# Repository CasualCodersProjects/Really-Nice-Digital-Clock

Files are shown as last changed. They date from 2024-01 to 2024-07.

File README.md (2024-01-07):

# Digital Clock Hardware

## Notice:
There is a hardware change between the 8 clocks sold on Tindie and these. The original production clocks from tindie are:  
- Missing a copper trace between the 3v3 line and the 3v3 output of the LDO. This is corrected with a hand-assembled solder bridge.  
- The I2C lines are shifted right by one pin. The tindie version uses GPIO21 for SDA and GPIO33 for SCL.  
- The Tindie clocks have a manually soldered bodge to move one of the binary coded digits off GPIO 46, which is an input only strapping pin.

## Description
This is an internet connected Clock which synchronizes with NTP servers to perpetually serve an accurate time. It is unable to keep very good time by itself. As such, it requires a stable, consistent network connection to show reliable time. With that, it should always be acctute within a second or so. To improve accuracy, you could modify the firmware to check every hour or half hour instead of once per day.  

It's built using BCD Decoders and 1.5" Seven segment displays for a nice clean look. It also utilizes an ambient light sensor to automatically brighten and dim to match the room light.  

This clock serves it's own webpage for configuration. Upon first boot, it activates an access point ssid `NiceClock`, password `MinesBigger`. Connect to the default gateway `192.168.4.1` to configure the clock and provide network credentials. Once credentials are provided, it should instantly connect and acquire the network time.  
To view the device's IP address, press the boot button on the rear.

## Hacking
This device openly exposes both a TTL UART and JTAG port on the rear of te board, near the ESP Module. You can also use the USB Port to program and upload code. While holding the boot button, then press reset. This enters the ESP32 into bootloader mode, and allows you to reflash new firmware or filesystem to the device.

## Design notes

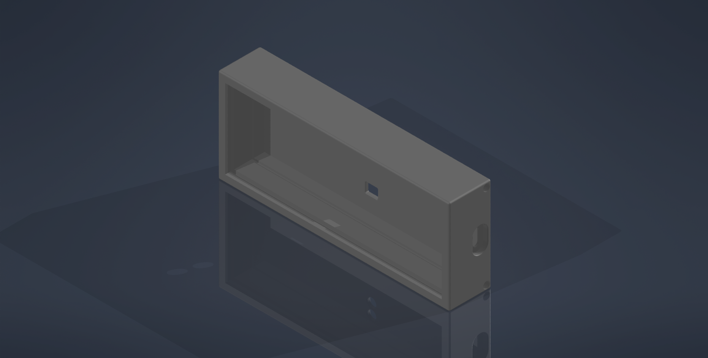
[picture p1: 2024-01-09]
Images/Case1.png

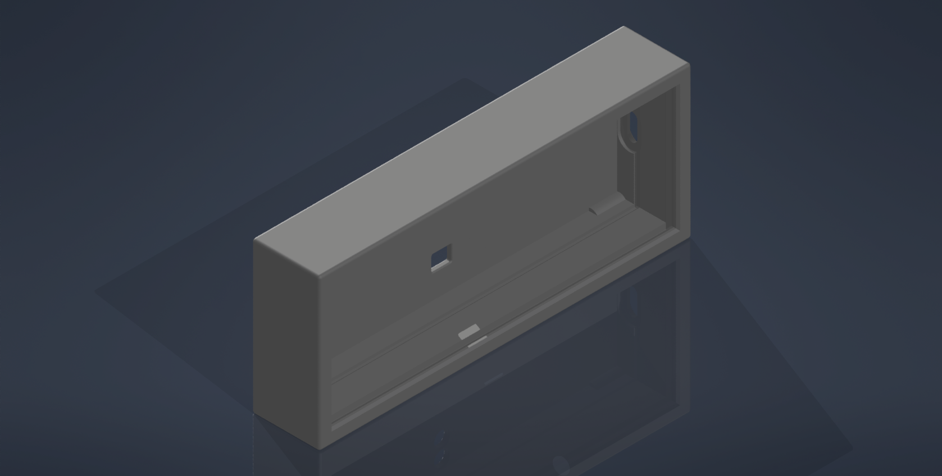
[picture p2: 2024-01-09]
Images/Case.png

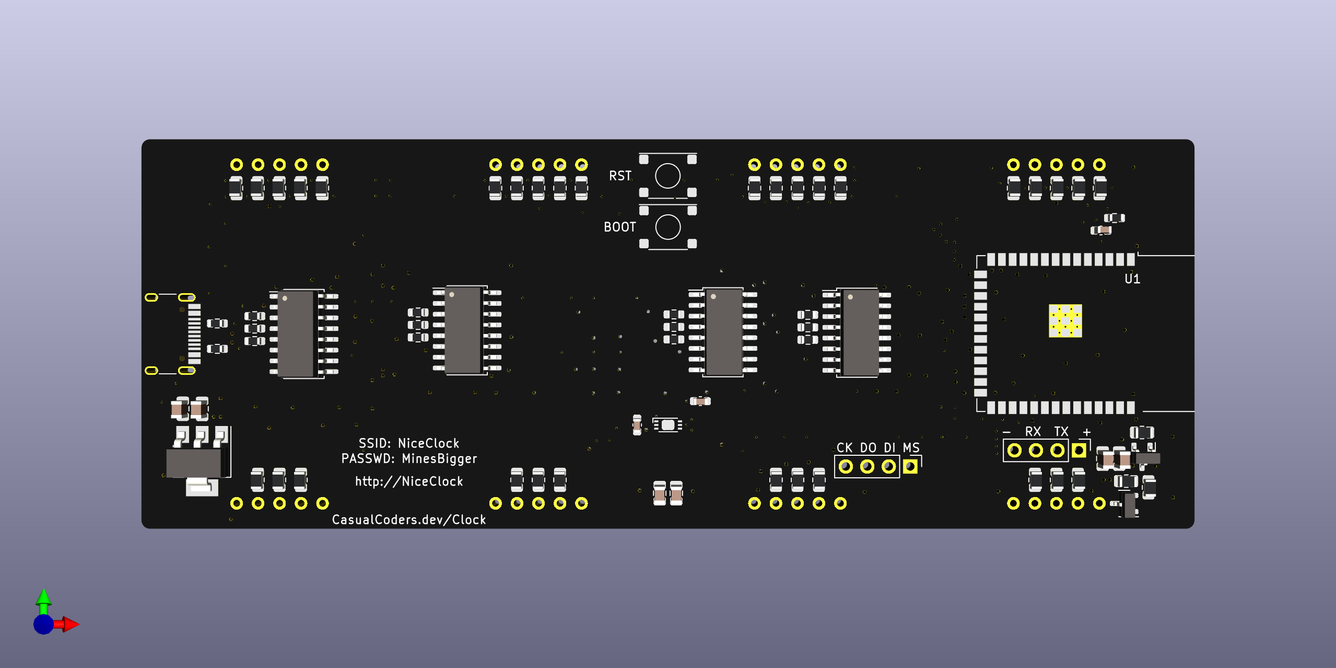
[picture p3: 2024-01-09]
Images/PCB_Render_RevB.png

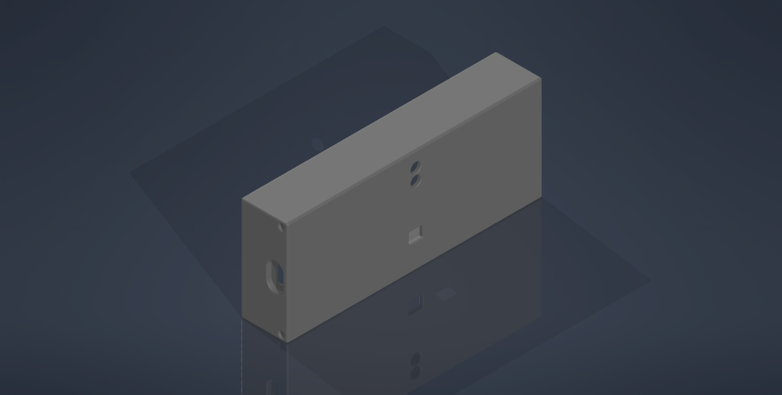
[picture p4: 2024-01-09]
Images/Case2.png

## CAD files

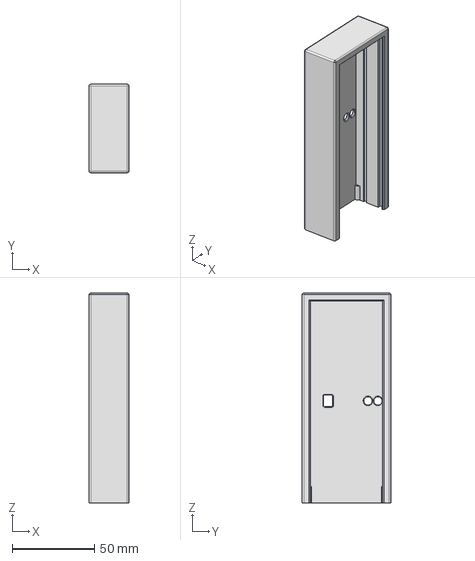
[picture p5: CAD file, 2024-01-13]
Case/V2.1 Case.stp
24.1 x 53.8 x 127.5 mm

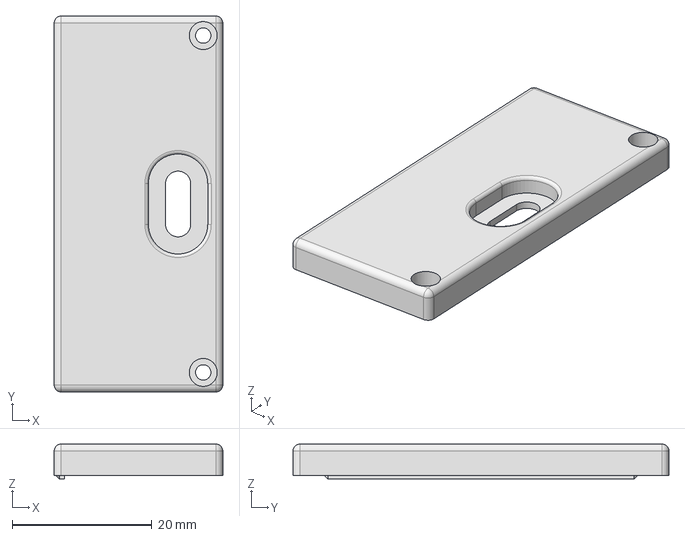
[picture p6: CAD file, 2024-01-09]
Case/V2.0 Lid.stp
24.1 x 53.8 x 5.00 mm

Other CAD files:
Case/V2.0 Lid.ipt
Case/V2.0 Lid.stl
Case/V2.1 Case.ipt
Case/V2.1 Case.stl

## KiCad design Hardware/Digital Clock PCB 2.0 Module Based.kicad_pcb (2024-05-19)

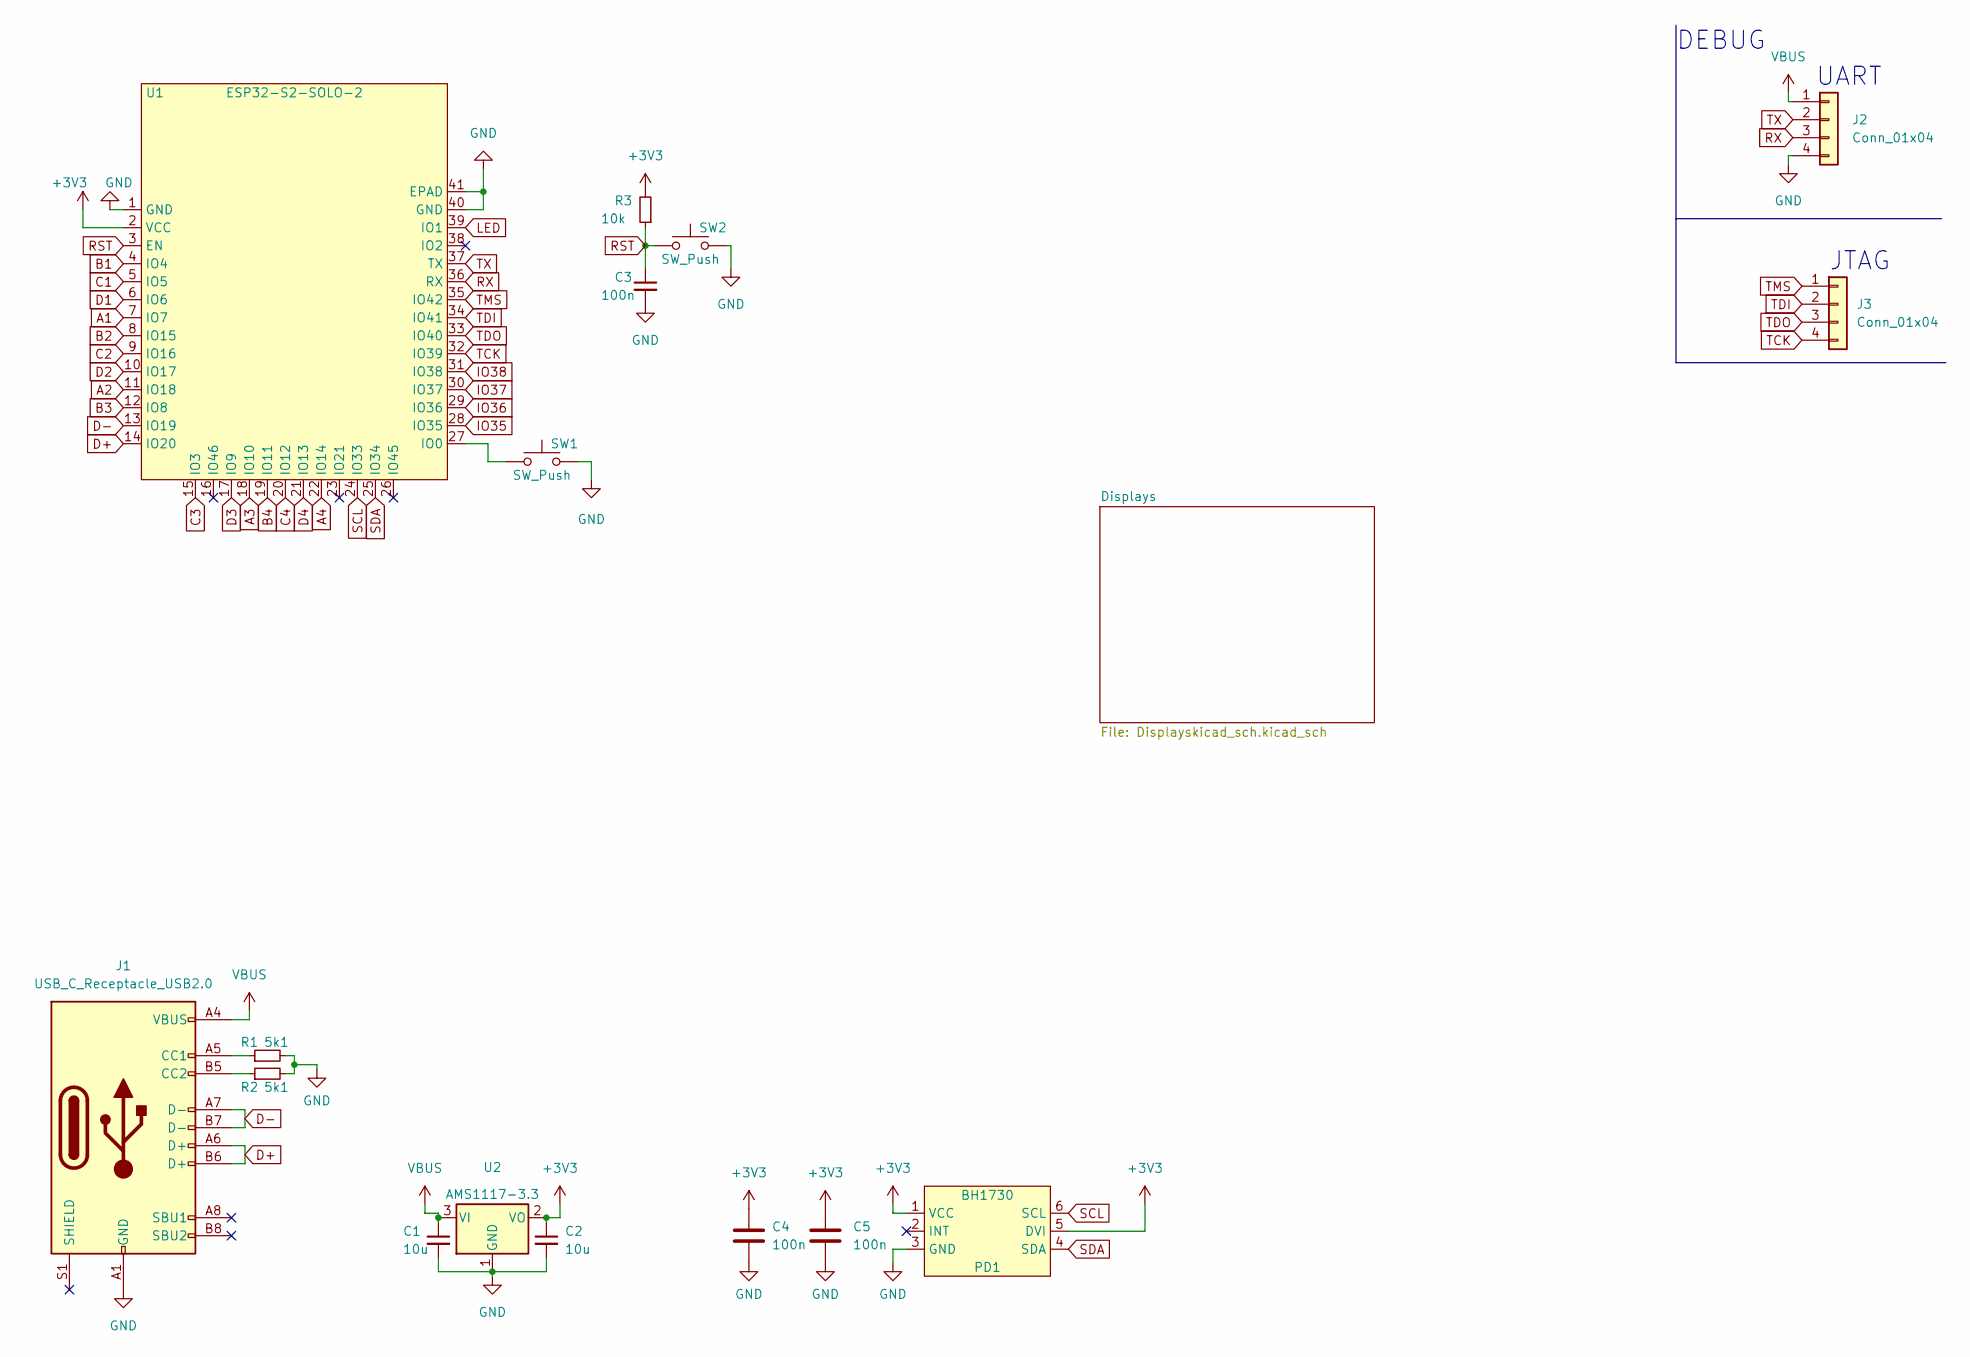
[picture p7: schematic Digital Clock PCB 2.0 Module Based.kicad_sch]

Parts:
C1, C2: 10u; C_0805_2012Metric
C3, C4, C5: 100n; C_0603_1608Metric
J1: USB_C_Receptacle_USB2.0; USB_C_Receptacle_HRO_TYPE-C-31-M-12
J2, J3: Conn_01x04; PinHeader_1x04_P2.54mm_Vertical
PD1: BH1730; WSOF6
R1, R2: 5k1; R_0603_1608Metric
R3: 10k; R_0603_1608Metric
SW1, SW2: SW_Push; 5.2mm_Tactile_Push_Button
U1: ESP32-S2-SOLO-2; ESP32-S3-WROOM-1
U2: AMS1117-3.3; SOT-223-3_TabPin2

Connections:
+3V3: C2.1, C4.1, C5.1, PD1.1 (VCC), PD1.5 (DVI), R3.2, U1.2 (VCC), U2.2 (VO); also elsewhere on the board
A1: U1.7 (IO7); also elsewhere on the board
A2: U1.11 (IO18); also elsewhere on the board
A3: U1.18 (IO10); also elsewhere on the board
A4: U1.22 (IO14); also elsewhere on the board
B1: U1.4 (IO4); also elsewhere on the board
B2: U1.8 (IO15); also elsewhere on the board
B3: U1.12 (IO8); also elsewhere on the board
B4: U1.19 (IO11); also elsewhere on the board
C1: U1.5 (IO5); also elsewhere on the board
C2: U1.9 (IO16); also elsewhere on the board
C3: U1.15 (IO3); also elsewhere on the board
C4: U1.20 (IO12); also elsewhere on the board
D1: U1.6 (IO6); also elsewhere on the board
D2: U1.10 (IO17); also elsewhere on the board
D3: U1.17 (IO9); also elsewhere on the board
D4: U1.21 (IO13); also elsewhere on the board
D+: J1.A6 (D+), J1.B6 (D+), U1.14 (IO20)
D-: J1.A7 (D-), J1.B7 (D-), U1.13 (IO19)
GND: C1.2, C2.2, C3.2, C4.2, C5.2, J1.A1 (GND), J1.A12 (GND), J1.B1 (GND), J1.B12 (GND), J2.4, PD1.3 (GND), R1.2, R2.2, SW1.2, SW2.2, U1.1 (GND), U1.40 (GND), U1.41 (EPAD), U2.1 (GND); also elsewhere on the board
IO35: U1.28 (IO35); also elsewhere on the board
IO36: U1.29 (IO36); also elsewhere on the board
IO37: U1.30 (IO37); also elsewhere on the board
IO38: U1.31 (IO38); also elsewhere on the board
LED: U1.39 (IO1); also elsewhere on the board
unnamed: J1.A5 (CC1), R1.1
unnamed: J1.B5 (CC2), R2.1
unnamed: SW1.1, U1.27 (IO0)
RST: C3.1, R3.1, SW2.1, U1.3 (EN)
RX: J2.3, U1.36 (RX)
SCL: PD1.6 (SCL), U1.24 (IO33)
SDA: PD1.4 (SDA), U1.25 (IO34)
TCK: J3.4, U1.32 (IO39)
TDI: J3.2, U1.34 (IO41)
TDO: J3.3, U1.33 (IO40)
TMS: J3.1, U1.35 (IO42)
TX: J2.2, U1.37 (TX)
VBUS: C1.1, J1.A4 (VBUS), J1.A9 (VBUS), J1.B4 (VBUS), J1.B9 (VBUS), J2.1, U2.3 (VI); also elsewhere on the board

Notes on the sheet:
DEBUG
UART
JTAG

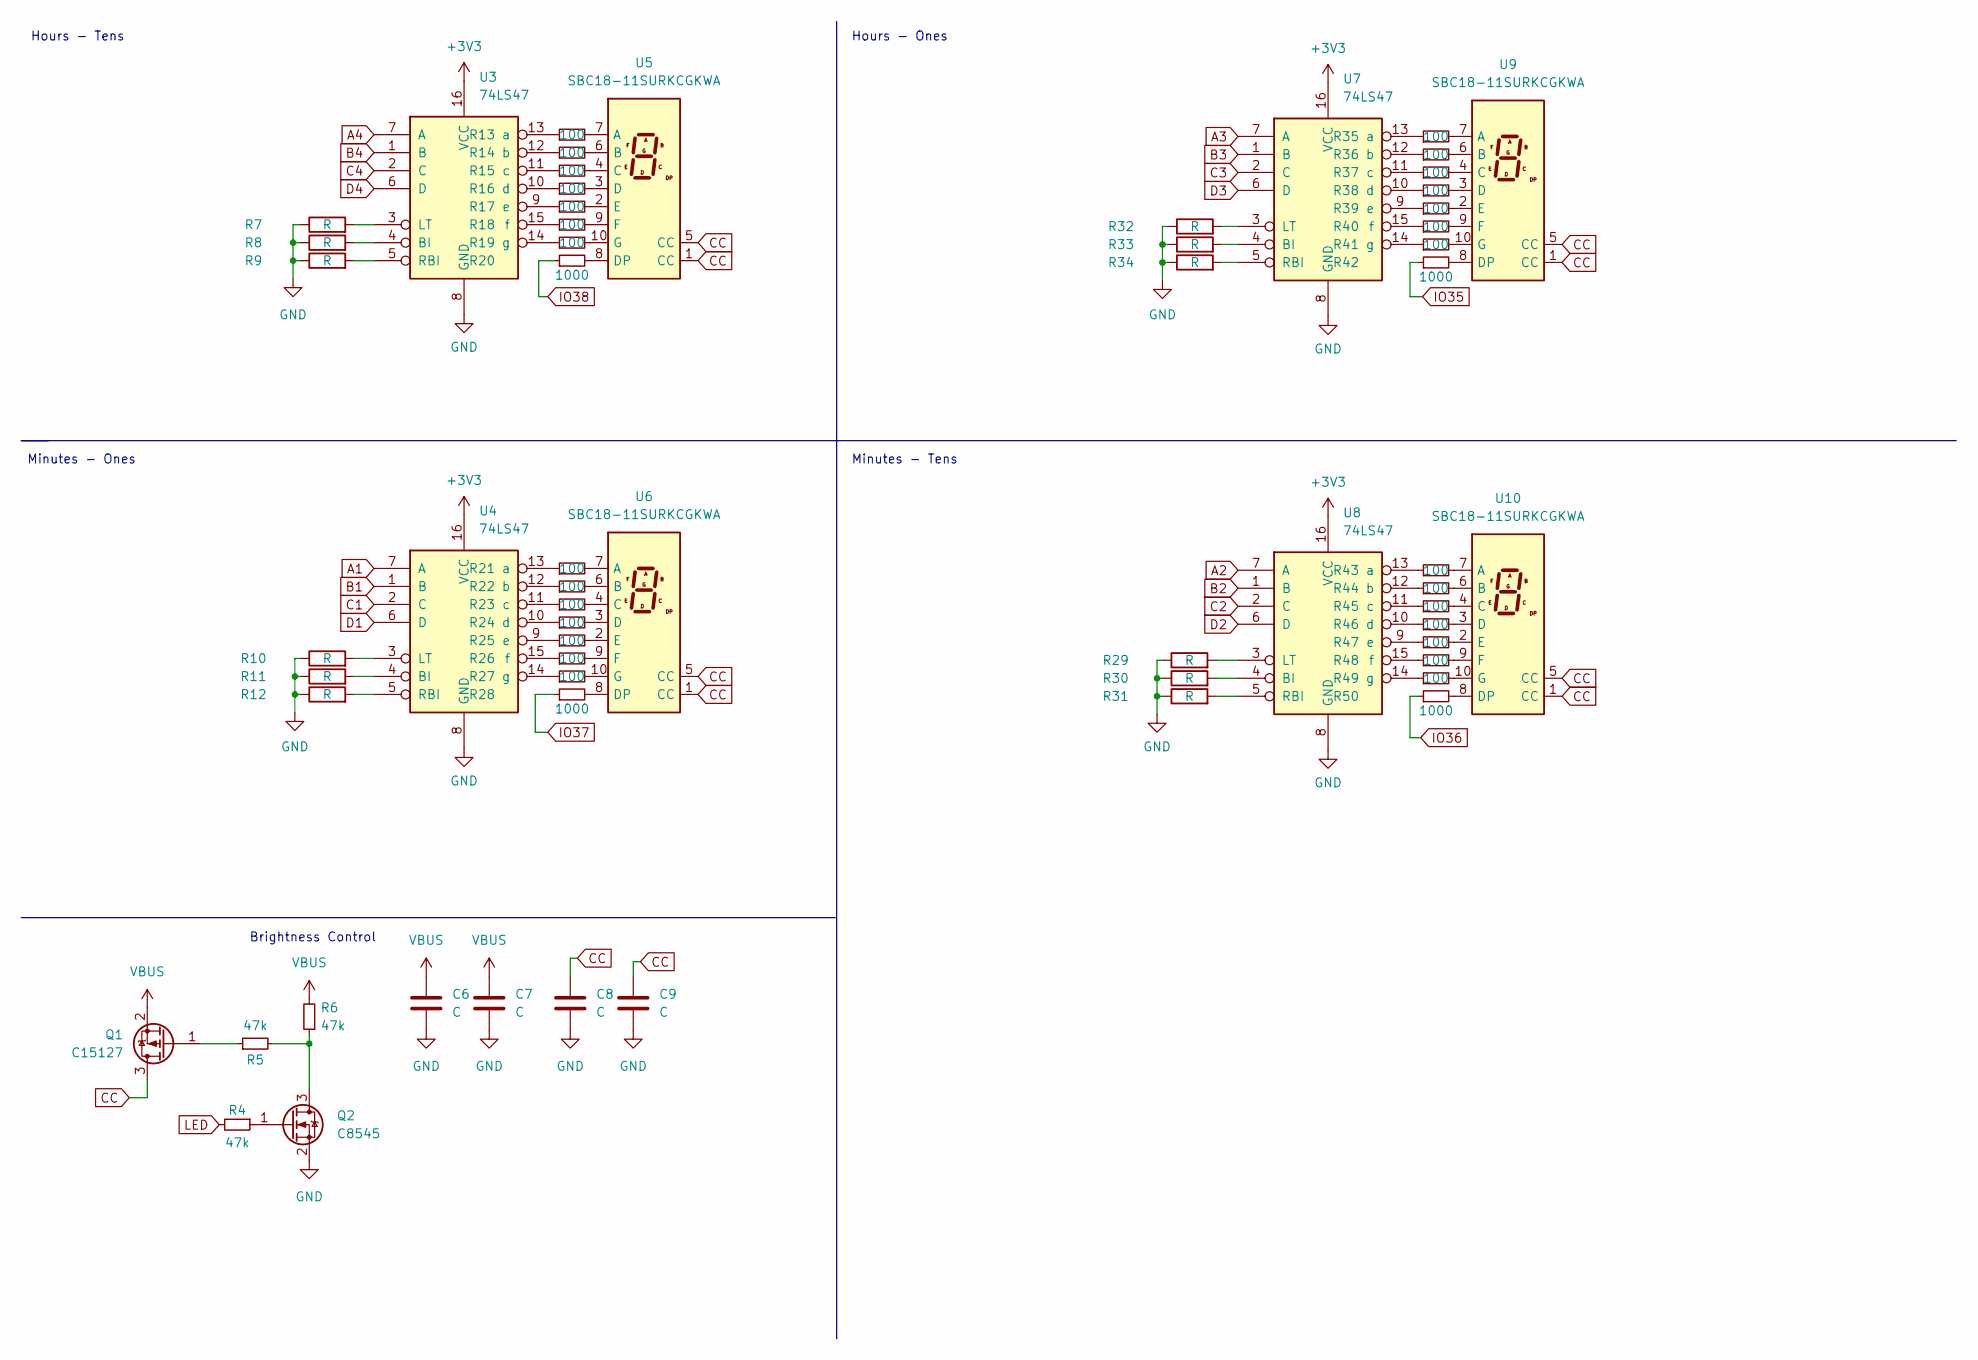
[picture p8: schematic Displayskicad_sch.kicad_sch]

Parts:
C6, C7, C8, C9: C; C_0805_2012Metric
Q1: C15127; SOT-23
Q2: C8545; SOT-23
R4, R5, R6: 47k; R_0805_2012Metric
R7, R8, R9, R10, R11, R12, R29, R30, R31, R32, R33, R34: R; R_0603_1608Metric
R13, R14, R15, R16, R17, R18, R19, R21, R22, R23, R24, R25, R26, R27, R35, R36, R37, R38, R39, R40, R41, R43, R44, R45, R46, R47, R48, R49: 100; R_0805_2012Metric
R20, R28, R42, R50: 1000; R_0805_2012Metric
U3, U4, U7, U8: 74LS47; SOIC-16_4.55x10.3mm_P1.27mm
U5, U6, U9, U10: SBC18-11SURKCGKWA; Segment_Display_1-5_inch

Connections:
+3V3: U3.16 (VCC), U4.16 (VCC), U7.16 (VCC), U8.16 (VCC); also elsewhere on the board
A1: U4.7 (A); also elsewhere on the board
A2: U8.7 (A); also elsewhere on the board
A3: U7.7 (A); also elsewhere on the board
A4: U3.7 (A); also elsewhere on the board
B1: U4.1 (B); also elsewhere on the board
B2: U8.1 (B); also elsewhere on the board
B3: U7.1 (B); also elsewhere on the board
B4: U3.1 (B); also elsewhere on the board
C1: U4.2 (C); also elsewhere on the board
C2: U8.2 (C); also elsewhere on the board
C3: U7.2 (C); also elsewhere on the board
C4: U3.2 (C); also elsewhere on the board
CC: C8.1, C9.1, Q1.3 (D), U5.1 (CC), U5.5 (CC), U6.1 (CC), U6.5 (CC), U9.1 (CC), U9.5 (CC), U10.1 (CC), U10.5 (CC)
D1: U4.6 (D); also elsewhere on the board
D2: U8.6 (D); also elsewhere on the board
D3: U7.6 (D); also elsewhere on the board
D4: U3.6 (D); also elsewhere on the board
GND: C6.2, C7.2, C8.2, C9.2, Q2.2 (S), R7.1, R8.1, R9.1, R10.1, R11.1, R12.1, R29.1, R30.1, R31.1, R32.1, R33.1, R34.1, U3.8 (GND), U4.8 (GND), U7.8 (GND), U8.8 (GND); also elsewhere on the board
IO35: R42.1; also elsewhere on the board
IO36: R50.1; also elsewhere on the board
IO37: R28.1; also elsewhere on the board
IO38: R20.1; also elsewhere on the board
LED: R4.2; also elsewhere on the board
unnamed: Q1.1 (G), R5.1
unnamed: Q2.3 (D), R5.2, R6.1
unnamed: Q2.1 (G), R4.1
unnamed: R8.2, U3.4 (BI)
unnamed: R7.2, U3.3 (LT)
unnamed: R9.2, U3.5 (RBI)
unnamed: R13.1, U3.13 (a)
unnamed: R14.1, U3.12 (b)
unnamed: R15.1, U3.11 (c)
unnamed: R16.1, U3.10 (d)
unnamed: R17.1, U3.9 (e)
unnamed: R18.1, U3.15 (f)
unnamed: R19.1, U3.14 (g)
unnamed: R11.2, U4.4 (BI)
unnamed: R10.2, U4.3 (LT)
unnamed: R12.2, U4.5 (RBI)
unnamed: R21.1, U4.13 (a)
unnamed: R22.1, U4.12 (b)
unnamed: R23.1, U4.11 (c)
unnamed: R24.1, U4.10 (d)
unnamed: R25.1, U4.9 (e)
unnamed: R26.1, U4.15 (f)
unnamed: R27.1, U4.14 (g)
unnamed: R13.2, U5.7 (A)
unnamed: R14.2, U5.6 (B)
unnamed: R15.2, U5.4 (C)
unnamed: R16.2, U5.3 (D)
unnamed: R20.2, U5.8 (DP)
unnamed: R17.2, U5.2 (E)
unnamed: R18.2, U5.9 (F)
unnamed: R19.2, U5.10 (G)
unnamed: R21.2, U6.7 (A)
unnamed: R22.2, U6.6 (B)
unnamed: R23.2, U6.4 (C)
unnamed: R24.2, U6.3 (D)
unnamed: R28.2, U6.8 (DP)
unnamed: R25.2, U6.2 (E)
unnamed: R26.2, U6.9 (F)
unnamed: R27.2, U6.10 (G)
unnamed: R33.2, U7.4 (BI)
unnamed: R32.2, U7.3 (LT)
unnamed: R34.2, U7.5 (RBI)
unnamed: R35.1, U7.13 (a)
unnamed: R36.1, U7.12 (b)
unnamed: R37.1, U7.11 (c)
unnamed: R38.1, U7.10 (d)
unnamed: R39.1, U7.9 (e)
unnamed: R40.1, U7.15 (f)
unnamed: R41.1, U7.14 (g)
unnamed: R30.2, U8.4 (BI)
unnamed: R29.2, U8.3 (LT)
unnamed: R31.2, U8.5 (RBI)
unnamed: R43.1, U8.13 (a)
unnamed: R44.1, U8.12 (b)
unnamed: R45.1, U8.11 (c)
unnamed: R46.1, U8.10 (d)
unnamed: R47.1, U8.9 (e)
unnamed: R48.1, U8.15 (f)
unnamed: R49.1, U8.14 (g)
unnamed: R35.2, U9.7 (A)
unnamed: R36.2, U9.6 (B)
unnamed: R37.2, U9.4 (C)
unnamed: R38.2, U9.3 (D)
unnamed: R42.2, U9.8 (DP)
unnamed: R39.2, U9.2 (E)
unnamed: R40.2, U9.9 (F)
unnamed: R41.2, U9.10 (G)
unnamed: R43.2, U10.7 (A)
unnamed: R44.2, U10.6 (B)
unnamed: R45.2, U10.4 (C)
unnamed: R46.2, U10.3 (D)
unnamed: R50.2, U10.8 (DP)
unnamed: R47.2, U10.2 (E)
unnamed: R48.2, U10.9 (F)
unnamed: R49.2, U10.10 (G)
VBUS: C6.1, C7.1, Q1.2 (S), R6.2; also elsewhere on the board

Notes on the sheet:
Hours - Tens
Hours - Ones
Minutes - Tens
Brightness Control
Minutes - Ones

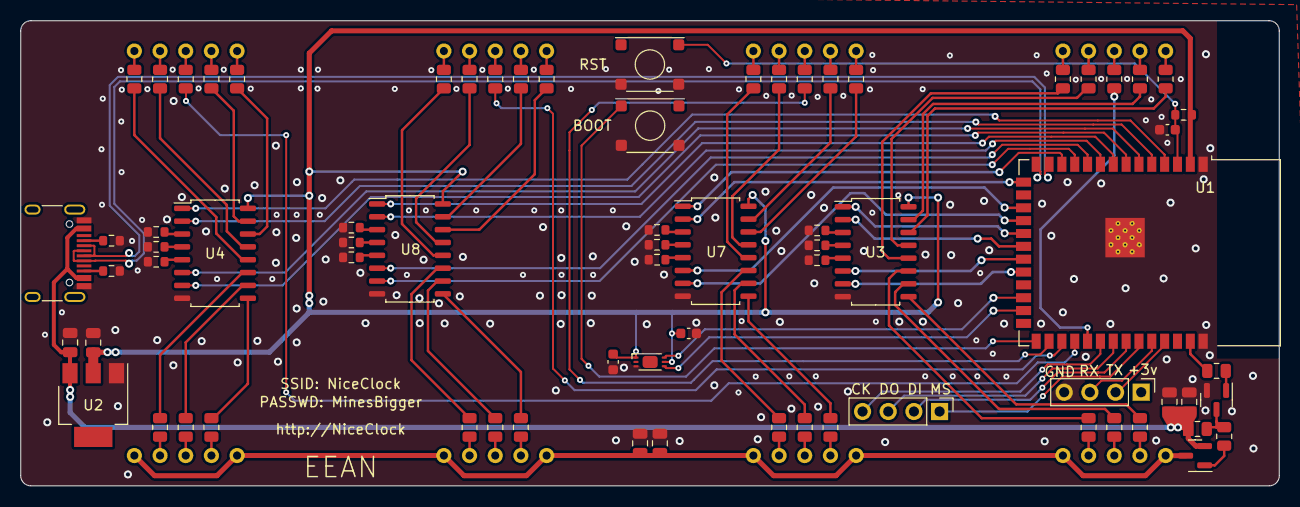
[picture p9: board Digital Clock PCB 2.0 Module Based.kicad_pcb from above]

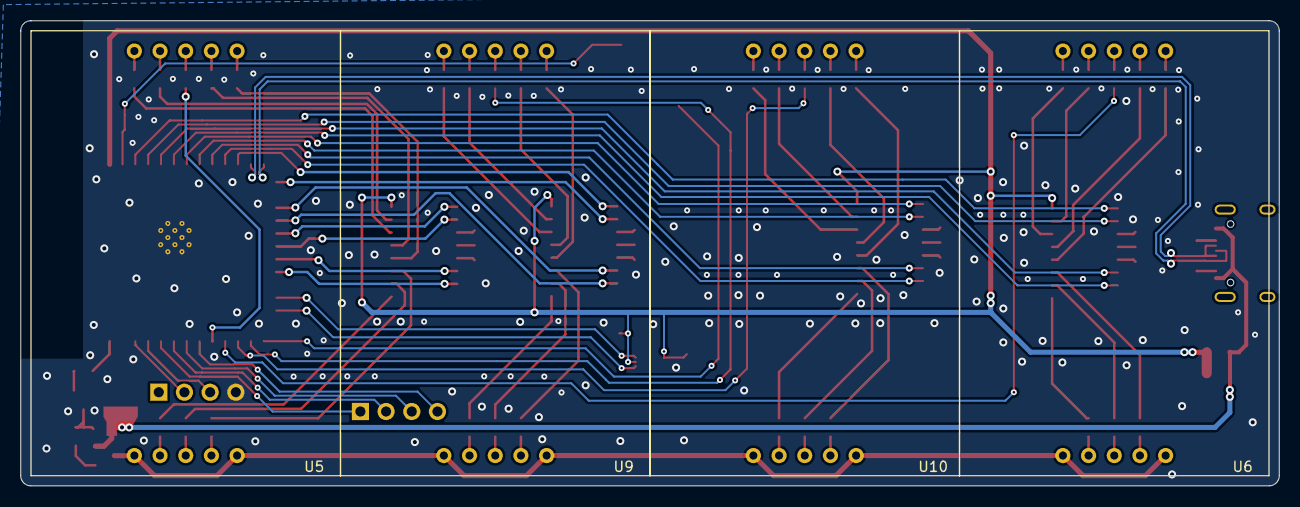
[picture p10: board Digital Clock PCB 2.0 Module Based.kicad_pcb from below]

Board: 2 copper layers, 124.5 x 46.0 mm, 77 parts (4 on the bottom side), 114 nets.

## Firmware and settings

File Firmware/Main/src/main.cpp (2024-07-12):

#include <Arduino.h>
#include <ArduinoJson.h>
#include <WiFi.h>
#include <Preferences.h>
#include <AsyncUDP.h>
#include <ESPAsyncWebServer.h>
#include <SPIFFS.h>
#include <Wire.h>
#include <NTPClient.h>
#include <time.h>
#include <movingAvg.h>  

// User Memory - WiFi SSID, PSK, Clock Configuration bits.
Preferences preferences;

// AccessPoint Credentials. Default UserMem WiFi Value.
const char* APID = "NiceClock";
const char* APSK = "MinesBigger";
const char* GARBAGE_STRING = "C!pbujKY2#4HXbcm5dY!WJX#ns29ff#vEDWmbZ9^d!QfBW@o%Trfj&sPENuVe&sx";

// Global Variables
bool softAPActive = 0;
bool showIP = 0;

// Server Stuff
WiFiUDP ntpUDP;
NTPClient timeClient(ntpUDP);
AsyncWebServer server(80);

// setting PWM properties
#define freq 2000
#define ledChannel 0
#define ledPWMResolution 8

// Pins used for segment displays
const int hours_pin[8] = {9, 8, 3, 14, 13, 10, 11, 12};
const int minutes_pin[8] = {7, 4, 5, 6, 18, 15, 16, 17};

// Additional Control Pins
const int ledPin = 1;       // Power pin for segment displays. Common Anode
const int decimalPin = 35;  // Decimal point which separates hours and minutes.
// Other Decimal Points on 36, 37, 38.

/// @brief Prints the time to 4 segment displays
/// @param hours integer number 0-99
/// @param minutes integer number 0-99
void printTime(int hours, int minutes){
  bool timeFormat = preferences.getBool("timeFormat", 1);
  // Serial.println(timeFormat);
  if (!timeFormat) {
    hours = (hours % 12) ?: 12;
  }

  // Break up the two digit integers to single digits.
  int hoursT = hours / 10;
  int hoursO = hours % 10;
  int minutesT = minutes / 10;
  int minutesO = minutes % 10;

  // Write binary coded decimal to each display.
  // Tens Place
  digitalWrite(hours_pin[4], (hoursT >> 0) & 1);  // A4
  digitalWrite(hours_pin[5], (hoursT >> 1) & 1);  // B4
  digitalWrite(hours_pin[6], (hoursT >> 2) & 1);  // C4
  digitalWrite(hours_pin[7], (hoursT >> 3) & 1);  // D4

  // Ones Place
  digitalWrite(hours_pin[0], (hoursO >> 0) & 1);   // A3
  digitalWrite(hours_pin[1], (hoursO >> 1) & 1);  // B3
  digitalWrite(hours_pin[2], (hoursO >> 2) & 1);  // C3
  digitalWrite(hours_pin[3], (hoursO >> 3) & 1);  // D3

  // Tens Place
  digitalWrite(minutes_pin[4], (minutesT >> 0) & 1);  // A2
  digitalWrite(minutes_pin[5], (minutesT >> 1) & 1);  // B2
  digitalWrite(minutes_pin[6], (minutesT >> 2) & 1);  // C2
  digitalWrite(minutes_pin[7], (minutesT >> 3) & 1);  // D2

  // Ones Place
  digitalWrite(minutes_pin[0], (minutesO >> 0) & 1);  // A1
  digitalWrite(minutes_pin[1], (minutesO >> 1) & 1);  // B1
  digitalWrite(minutes_pin[2], (minutesO >> 2) & 1);  // C1
  digitalWrite(minutes_pin[3], (minutesO >> 3) & 1);  // D1
}

// Flag the main loop to show the IP Address of the clock.
static void IRAM_ATTR showIPFlag(){
  showIP = 1;
}

/// @brief Flashes the IP Address of the device on the main display.
/// @param localIP IPAddres object. Basically an array of 8 bit integers.
void displayIP(IPAddress localIP) {
  pinMode(38, OUTPUT);
  digitalWrite(decimalPin, 1);
  digitalWrite(38, 0);

  int octet0 = localIP[0];
  int octet1 = localIP[1];
  int octet2 = localIP[2];
  int octet3 = localIP[3];

  printTime(octet0 / 100, octet0 % 100);
  delay(1500);
  printTime(octet1 / 100, octet1 % 100);
  delay(1500);
  printTime(octet2 / 100, octet2 % 100);
  delay(1500);
  printTime(octet3 / 100, octet3 % 100);
  delay(1500);

  digitalWrite(decimalPin, 0);
  pinMode(38, INPUT);
}

/// @brief Initializes BH1730 Ambient Light Sensor over I2C.
void initLightSensor() {
  Wire.beginTransmission(0x29);
  Wire.write(0x80);
  Wire.write(0x3);
  Wire.endTransmission();
}

/// @brief Reads the ambient light bits inside the ambient light sensor
/// @return 8 bit integer mapped between the user setable min and max brightness values.
uint8_t readAmbientLightData(){
  Wire.beginTransmission(0x29);
  Wire.write(0b10010100);
  Wire.endTransmission();
  Wire.requestFrom(0x29, 2);

  // Read the data from the BH1730
  byte highByte = Wire.read();
  byte lowByte = Wire.read();

  // Combine the high and low bytes to get the ambient light level
  int lightLevel = (highByte << 8) | lowByte;

  // return the ambient light level
  return( map(lightLevel, 0, 65535, preferences.getInt("minBrightness", 10), preferences.getInt("maxBrightness", 255)) );
}

// Moving average to smooth out changes in the ambient light.
movingAvg ambientLight(10);

// Initial Setup Function
void setup() {
  // Serial for debug. Preferences for UserMem.
  Serial.begin(9600);
  Serial.println("Entered setup");
  preferences.begin("usermem");
  Serial.println("Begin EEPROM");
  SPIFFS.begin();

  setenv("TZ", preferences.getString("timezone", "UTC").c_str(), 1);
  tzset();
  ledcSetup(ledChannel, freq, ledPWMResolution);
  ledcAttachPin(ledPin, ledChannel);
  ledcWrite(ledChannel, 50);

  // Begin I2C on pins 34, 33.
  Wire.begin(33, 21);
  initLightSensor();
  ambientLight.begin();

  // Fill moving average with real data.
  // Prevents the clock from bouncing around in brightness.
  for (int i = 0; i < 10; i++) {
    ambientLight.reading(readAmbientLightData());
  }

  // Activate the decimal point as hour indicator.
  pinMode(decimalPin, OUTPUT);
  digitalWrite(decimalPin, 0);

  // Set the hours and minutes pins to output mode
  for (int i = 0; i < 8; i++) {
    pinMode(hours_pin[i], OUTPUT);
    pinMode(minutes_pin[i], OUTPUT);
  }
  
  // ---------- WiFi Section ----------
  // Access Point init
  Serial.println("Start Access Point");
  WiFi.softAPsetHostname("niceclock");
  WiFi.mode(WIFI_AP_STA);
  WiFi.softAP(APID, APSK);
  softAPActive = true;

  // Skip WiFi configuration if no credentials exist.
  if (preferences.getString("WiFiSSID", GARBAGE_STRING) == GARBAGE_STRING || preferences.getString("WiFiPSK", GARBAGE_STRING) == GARBAGE_STRING) {
    Serial.println("WiFi not configured. Skipping network connection.");
  }

  // WiFi Credentials exist. Configure WiFi and attempt to connect.
  else {
    Serial.println("WiFi Configured. Attempting Connection.");
   
    // Begin WiFi with the stored credentials.
    WiFi.setHostname("niceclock");
    WiFi.begin(preferences.getString("WiFiSSID", GARBAGE_STRING).c_str(), preferences.getString("WiFiPSK", GARBAGE_STRING).c_str());
    
    // Attempt to connect for ~5 seconds before continuing.
    while(!WiFi.isConnected() && millis() < 5000) {
      Serial.print(". ");
      delay(100);
    }
    Serial.println();

    // Connection Successful. Teardown and disable AP.
    if (WiFi.isConnected()){
      Serial.println("\nConnection Success. Tearing down AP.");
      WiFi.softAPdisconnect();
      WiFi.mode(WIFI_STA);
      softAPActive = false;
      displayIP(WiFi.localIP());
    }

    // Connection unsuccessful. Continue to main loop.
    // Your WiFi is slow, down, or you incorrectly configured your credentials if you're at this point.
    else{
      Serial.println("\nConnection Failed. Please connect to the webportal and enter valid information.");
    }
  }

  // Shows the center point for the clock. Splitter between hour and minute.
  digitalWrite(decimalPin, 0);

  // Begin Time Keeping
  timeClient.begin();
  timeClient.update();

  // ---------- Webpage Configuration Section ----------
  server.on("/", HTTP_GET, [](AsyncWebServerRequest *request){
    request->send(SPIFFS, "/index.html", String(), false);
  });

  // Route to load style.css file
  server.on("/milligram.min.css", HTTP_GET, [](AsyncWebServerRequest *request){
    Serial.println("Loading BS CSS");
    request->send(SPIFFS, "/milligram.min.css", "text/css");
  });

  // Route to load TimeZone information.
  server.on("/zones.csv", HTTP_GET, [](AsyncWebServerRequest *request){
    Serial.println("Loading zones");
    request->send(SPIFFS, "/zones.csv", "text/csv");
  });

  // Handle HTTP POST requests for the root page
  server.on("/updateWiFi", HTTP_POST, [](AsyncWebServerRequest *request){
    Serial.println("Request Received");

    // Handling input data from the webpage. ALL EEPROM Values updated
    if (request->hasParam("ssid", true) && request->hasParam("psk", true)) {
      String ssid = request->getParam("ssid", true)->value();
      String psk = request->getParam("psk", true)->value();
      if(ssid != ""){
        Serial.println("Updating WiFi Credentials to SSID: " + ssid);
        preferences.putString("WiFiSSID", ssid);
        preferences.putString("WiFiPSK", psk);

        // Begin WiFi with the stored credentials.
        WiFi.setHostname("niceclock");
        WiFi.begin(preferences.getString("WiFiSSID", GARBAGE_STRING).c_str(), preferences.getString("WiFiPSK", GARBAGE_STRING).c_str());
      }
    }

    // Done
    request->send(200);
  });

  // Toggle between 12h and 24h format.
  server.on("/updateTimeFormat", HTTP_POST, [](AsyncWebServerRequest *request) {
    // Handling input data from the webpage
    if (request->hasArg("isChecked")) {
      String isChecked = request->arg("isChecked");
      if (isChecked == "true") {
        preferences.putBool("timeFormat", 0);
      } else {
        preferences.putBool("timeFormat", 1);
      }
    }

    request->send(200);
  });

  // Route to get configured time format (12|24)
  server.on("/getTimeFormat", HTTP_GET, [](AsyncWebServerRequest *request){
    String checkboxStateStr = preferences.getBool("timeFormat", 1) ? "false" : "true";
    request->send(200, "text/plain", checkboxStateStr);
  });

  // Route to get configured WiFi SSID
  server.on("/getWiFiSSID", HTTP_GET, [](AsyncWebServerRequest *request){
    String wiFiSSID = preferences.getString("WiFiSSID", "");
    request->send(200, "text/plain", wiFiSSID);
  });

  // Route to get configured Minimum Brightness
  server.on("/getMinBrightness", HTTP_GET, [](AsyncWebServerRequest *request){
    String minBrightness = String(preferences.getInt("minBrightness", 10));
    request->send(200, "text/plain", minBrightness);
  });

  // Route to get configured Maximum Brightness
  server.on("/getMaxBrightness", HTTP_GET, [](AsyncWebServerRequest *request){
    String maxBrightness = String(preferences.getInt("maxBrightness", 255));
    request->send(200, "text/plain", maxBrightness);
  });

  // Route to get update ESP-Side Brightness limits.
  server.on("/updateBrightness", HTTP_POST, [](AsyncWebServerRequest *request){
    Serial.println("Request Received");

    // Handling input data from the webpage. ALL EEPROM Values updated
    if (request->hasParam("minBrightnessSlider", true) && request->hasParam("maxBrightnessSlider", true)) {
      int min = request->getParam("minBrightnessSlider", true)->value().toInt();
      int max = request->getParam("maxBrightnessSlider", true)->value().toInt();

      preferences.putInt("minBrightness", min);
      preferences.putInt("maxBrightness", max);
    }

    // Done
    request->send(200);
  });

  // Route to update timezone.
  server.on("/setTZ", HTTP_POST, [](AsyncWebServerRequest *request){
    Serial.println("Request Received");

    // Handling input data from the webpage
    if (request->hasArg("timezone")) {
      String timezone = request->arg("timezone");
      preferences.putString("timezone", timezone);
      configTzTime(timezone.c_str(), "pool.ntp.org");
      timeClient.update();
    }

    // Done
    request->send(200);
  });

  // Start the server
  server.begin();

  // Use an interrupt to flag when the boot button has been pressed.
  attachInterrupt(0, showIPFlag, FALLING);
}


void loop() {
  // Connection Successful. Teardown and disable AP.
  if(softAPActive && WiFi.isConnected()){
    Serial.println("Internet Connected. Tearing down AP.");
    WiFi.softAPdisconnect();
    WiFi.mode(WIFI_STA);
    softAPActive = false;
    timeClient.update();
  }

  // Lost connection to the internet. Re-Enable the AP to avoid getting stuck.
  if(!softAPActive && !WiFi.isConnected()) {
    Serial.println("Lost Internet. Restarting AP.");
    WiFi.softAPsetHostname("niceclock");
    WiFi.mode(WIFI_AP_STA);
    WiFi.softAP(APID, APSK);
    softAPActive = true;
  }

  // Reconnect to NTP To update time at midnight every night
  if(timeClient.getHours() == 0 && timeClient.getMinutes() == 0 && timeClient.getSeconds() == 0){
    timeClient.update();
    delay(1000);
  }

  // Base the time on epoch. This allows DST To work automatically.
  time_t now = timeClient.getEpochTime();
  struct tm *timeinfo = localtime(&now);

  // Print the timezone info to SSDs
  printTime(timeinfo->tm_hour, timeinfo->tm_min);

  // Adjust light intensity using a moving average
  if ((millis() % 25) == 0) {
    uint8_t ambiReading = ambientLight.reading(readAmbientLightData());
    // Serial.println(ambiReading);
    ledcWrite(ledChannel, ambiReading);
  }

  // Display IP if button flagged
  if (showIP){
    displayIP(WiFi.localIP());
    showIP = 0;
  }
}

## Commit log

2023-06-26 add 3d printable case files
    [Clock V1.0 Case.stl, Clock V1.0 Lid.stl]
2023-06-26 Add Version 2.0 of the hardware and software
    [BOM-Digital Clock PCB.csv, Clock V1.0 Case.stl, Clock V1.0 Lid.stl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]
2023-10-02 Unknown changes. Something probably
    [zones.csv]
2024-01-07 Updated Hardware and folder names
    [Digital Clock PCB 2.0 Module Based-CuBottom.gbr, Digital Clock PCB 2.0 Module Based-CuTop.gbr, Digital Clock PCB 2.0 Module Based-EdgeCuts.gbr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]
2024-01-09 Correct spelling mistake. Rename folders.
    [Digital Clock PCB 2.0 Module Based.kicad_pcb, Digital Clock PCB 2.0 Module Based.kicad_sch, Displayskicad_sch.kicad_sch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]
2024-01-09 3D files and product images
    [V2.0 Case.ipt, V2.0 Case.stl, V2.0 Case.stp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]
2024-01-13 Add cutout for antenna in case
    [V2.0 Case.ipt, V2.0 Case.stl, V2.0 Case.stp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]
2024-01-17 Revert main.cpp to real release code
    [main.cpp]
2024-05-19 Move firmware down a directory. Add Integration test. Requires gitignored file containing wifi credentials.
    [Digital Clock PCB 2.0 Module Based.kicad_pcb, zones.csv]
